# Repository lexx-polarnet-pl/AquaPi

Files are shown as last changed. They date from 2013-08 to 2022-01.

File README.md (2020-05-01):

# AquaPi

The aim of this project is to build Raspberry Pi controlled platform for aquarium management.

## Table of contents
* [General info](#general-info)
* [Screenshots](#screenshots)
* [Versions](#Versions)
* [Setup](#setup)
* [Features](#features)
* [Status](#status)
* [Inspiration](#inspiration)
* [Contact](#contact)

## General info
This project is licensed using GPL 2.0 version.
It's combination of hardware layer and software as well.
Structure of directories is following:

* Software - source codes of daemon and php web ui.
* Hardware - all hardware designs (created using KiCad).
* Doc      - place for documentation.

You can like it or not, but software is written (and documentation as well) in Polish language.

## Screenshots
Main screen

## Versions
* Version 1.0 - still one and only stable version that was released.
* Version 2.0 - aka still in development phase - far more advanced than previous one, but also still not finished (but quite stable).

## Setup
Please see Doc directory if you wish to learn more about setup process.

## Features
List of features ready:
* Heating/cooling tank with different temperature settings between night and day.
* Light control with PWM usage to simulate sunrise/dawn.
* Recording of statistical data collected from sensors into database, and visualization on charts.
* Can be controlled using web browser, both on PC and mobile phone.
* Outputs controlled with timers with 1 second accuracy (nice for DIY feeders or fertilizers).

TODOs for future development:
* still some stuff to do with CO&#8322;.
* and probably more small staff to do.

## Status
Project is: in progress.

## Inspiration
This project was inspired by [Aquamat](https://github.com/musashimm/aquamat). 

## Contact
Created by [lexx](mailto:lexx@polarnet.pl) (https://lexx.polarnet.pl/) - feel free to contact me!
AquaPi is also having its own home page - see https://aquapi.polarnet.pl/

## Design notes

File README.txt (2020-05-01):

AquaPi
======

Ten projekt ma na celu zbudowanie interface'u (sprzętowego i oprogramowania)
tak, aby zamienić Raspberry Pi w komputer sterujący akwarium.

Wszystkie źródła są objęte licencją GPLv2.

Katalogi:

* Software - miejsce na kody źródłowe (daemona oraz interface php)
* Hardware - miejsce na schematy sprzętu
* Doc      - miejsce na dokumentację

Schematy jak i płytki projektowane są w KiCad

Pozdrawiam,
Marcin 'Lexx' Król
http://lexx.polarnet.pl
lexx@polarnet.pl

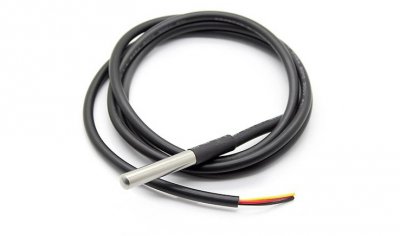
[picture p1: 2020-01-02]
Doc/html/hardware/DS18B20-wp.jpg

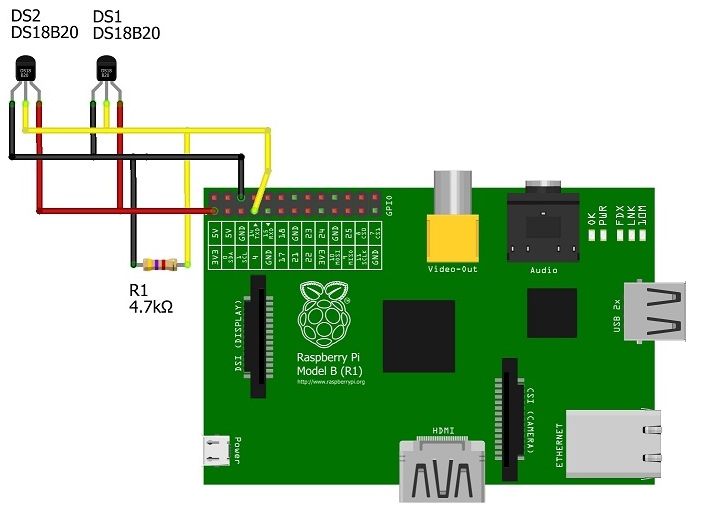
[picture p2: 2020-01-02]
Doc/html/hardware/DS18B20-wire.jpg

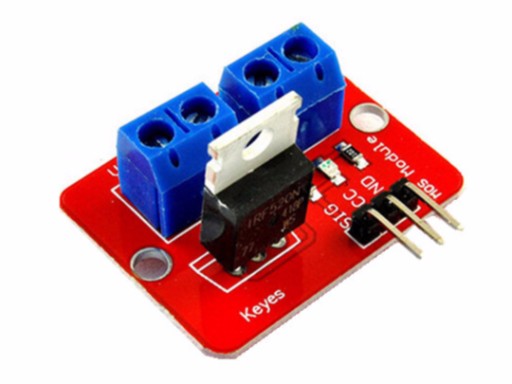
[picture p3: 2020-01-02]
Doc/html/hardware/MOSFET.jpg

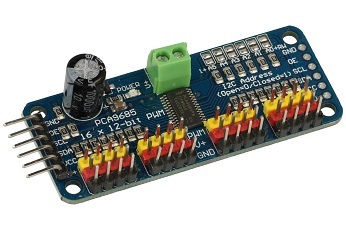
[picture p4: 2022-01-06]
Doc/html/hardware/PCA9685.jpg

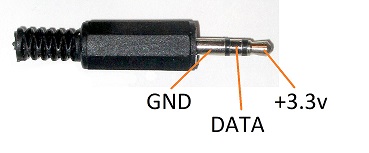
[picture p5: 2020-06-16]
Doc/html/hardware/AQUAPI_connector_jack3.5.jpg

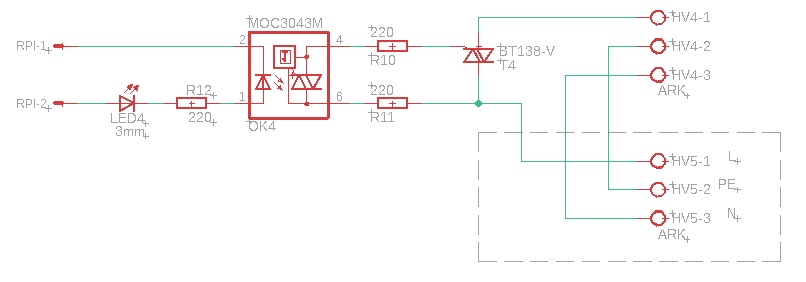
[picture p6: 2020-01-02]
Doc/html/hardware/TRIAK-wire.jpg

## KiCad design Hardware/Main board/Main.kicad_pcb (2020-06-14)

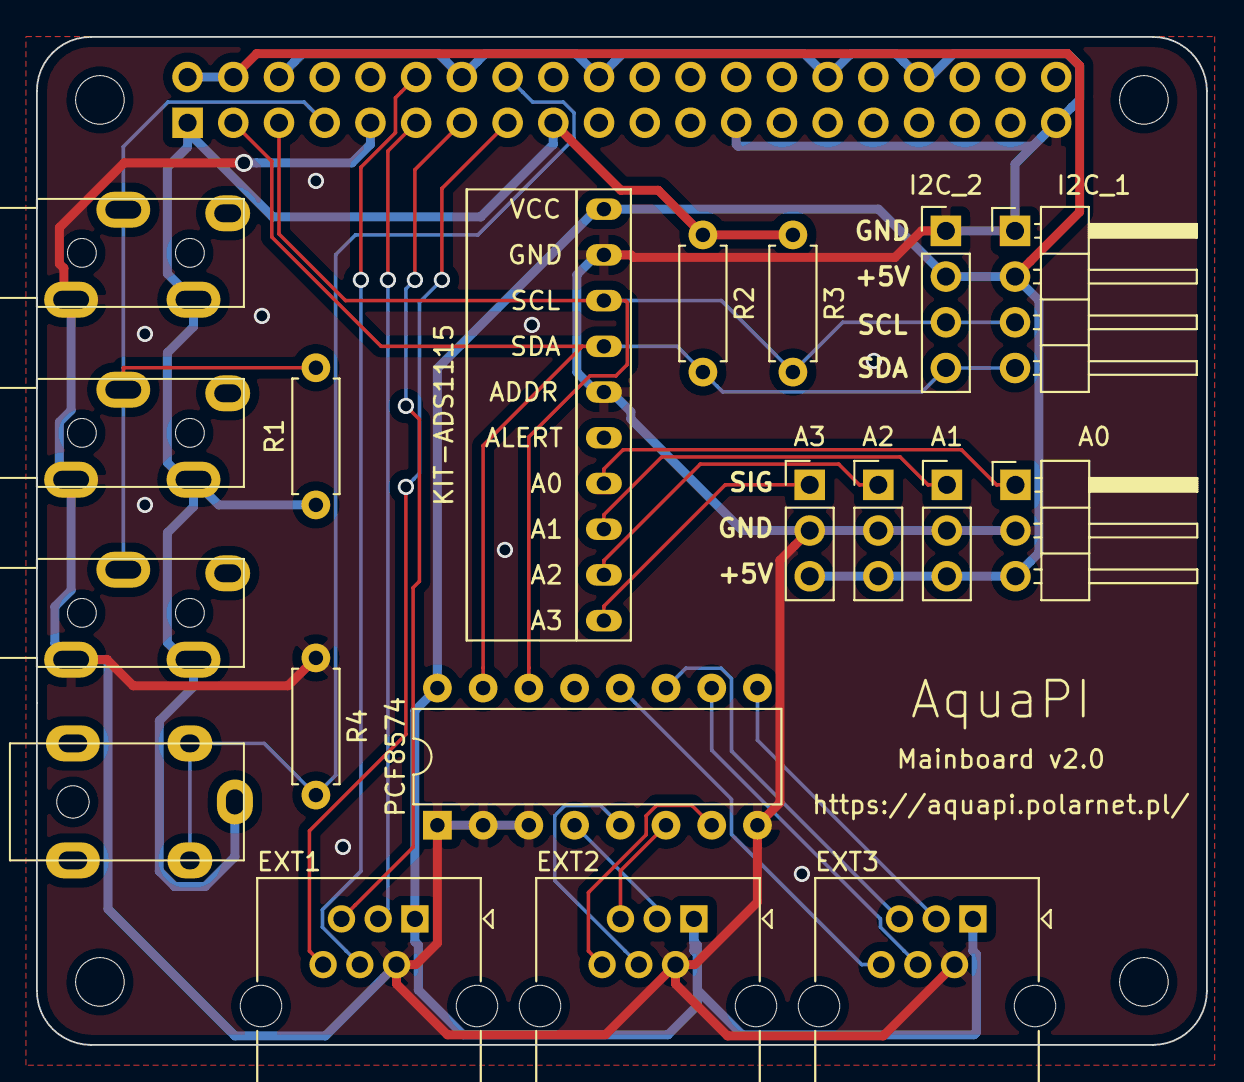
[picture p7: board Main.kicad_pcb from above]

Board: 2 copper layers, 65.0 x 56.0 mm, 24 parts (1 on the bottom side), 23 nets.

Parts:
A0: ADC_A; Pin_Header_Angled_1x03_Pitch2.54mm
A1: ADC_B; Pin_Header_Straight_1x03_Pitch2.54mm
A2: ADC_C; Pin_Header_Straight_1x03_Pitch2.54mm
A3: ADC_D; Pin_Header_Straight_1x03_Pitch2.54mm
EXT1, EXT2, EXT3: RJ12; RJ25_Wayconn_MJEA-660X1_Horizontal
I2C_1: Conn_01x04_Male; Pin_Header_Angled_1x04_Pitch2.54mm
I2C_2: Conn_01x04_Male; Pin_Header_Straight_1x04_Pitch2.54mm
J1, J2, J3: PJ-327
J4: Barrel_Jack_Switch; DC-1GDC1.7_4.0K2
KIT-ADS1115: ADS1115IDGS; ADS1115-KIT
MK1, MK2, MK3, MK4: M2.5; MountingHole_2.7mm_M2.5
P1: Conn_02x20_Odd_Even; PinSocket_2x20_P2.54mm_Vertical
PCF8574: PCF8574; DIP-16_W7.62mm
R1, R2, R3, R4: 4,7k; R_Axial_DIN0207_L6.3mm_D2.5mm_P7.62mm_Horizontal

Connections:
+3V3: J1.3, J2.3, J3.3, J4.1, P1.1, P1.17, R1.1, R2.1, R3.1
+5V: A0.3, A1.3, A2.3, A3.3, EXT1.1, EXT2.1, EXT3.1, I2C_1.2, I2C_2.2, KIT-ADS1115.8, P1.2, P1.4, PCF8574.16
/GPIO2(SDA1): I2C_1.4, I2C_2.4, KIT-ADS1115.9, P1.3, PCF8574.15, R2.2
/GPIO3(SCL1): I2C_1.3, I2C_2.3, KIT-ADS1115.10, P1.5, PCF8574.14, R3.2
/GPIO4(GCLK): J1.2, J2.2, J3.2, P1.7, R1.2
/GPIO17(GEN0): EXT1.3, P1.11
/GPIO18(GEN1)(PWM0): EXT1.4, P1.12
/GPIO22(GEN3): EXT1.6, P1.15
/GPIO23(GEN4): J4.2, J4.3, P1.16, R4.2
/GPIO27(GEN2): EXT1.5, P1.13
GND: A0.2, A1.2, A2.2, A3.2, EXT1.2, EXT2.2, EXT3.2, I2C_1.1, I2C_2.1, J1.1, J2.1, J3.1, KIT-ADS1115.1, KIT-ADS1115.3, P1.6, P1.9, P1.14, P1.20, P1.25, P1.30, P1.34, P1.39, PCF8574.1, PCF8574.2, PCF8574.3, PCF8574.8, R4.1
unnamed: A0.1, KIT-ADS1115.4
unnamed: A1.1, KIT-ADS1115.5
unnamed: A2.1, KIT-ADS1115.6
unnamed: A3.1, KIT-ADS1115.7
unnamed: EXT2.3, PCF8574.4
unnamed: EXT2.4, PCF8574.5
unnamed: EXT2.5, PCF8574.6
unnamed: EXT2.6, PCF8574.7
unnamed: EXT3.3, PCF8574.9
unnamed: EXT3.4, PCF8574.10
unnamed: EXT3.5, PCF8574.11
unnamed: EXT3.6, PCF8574.12

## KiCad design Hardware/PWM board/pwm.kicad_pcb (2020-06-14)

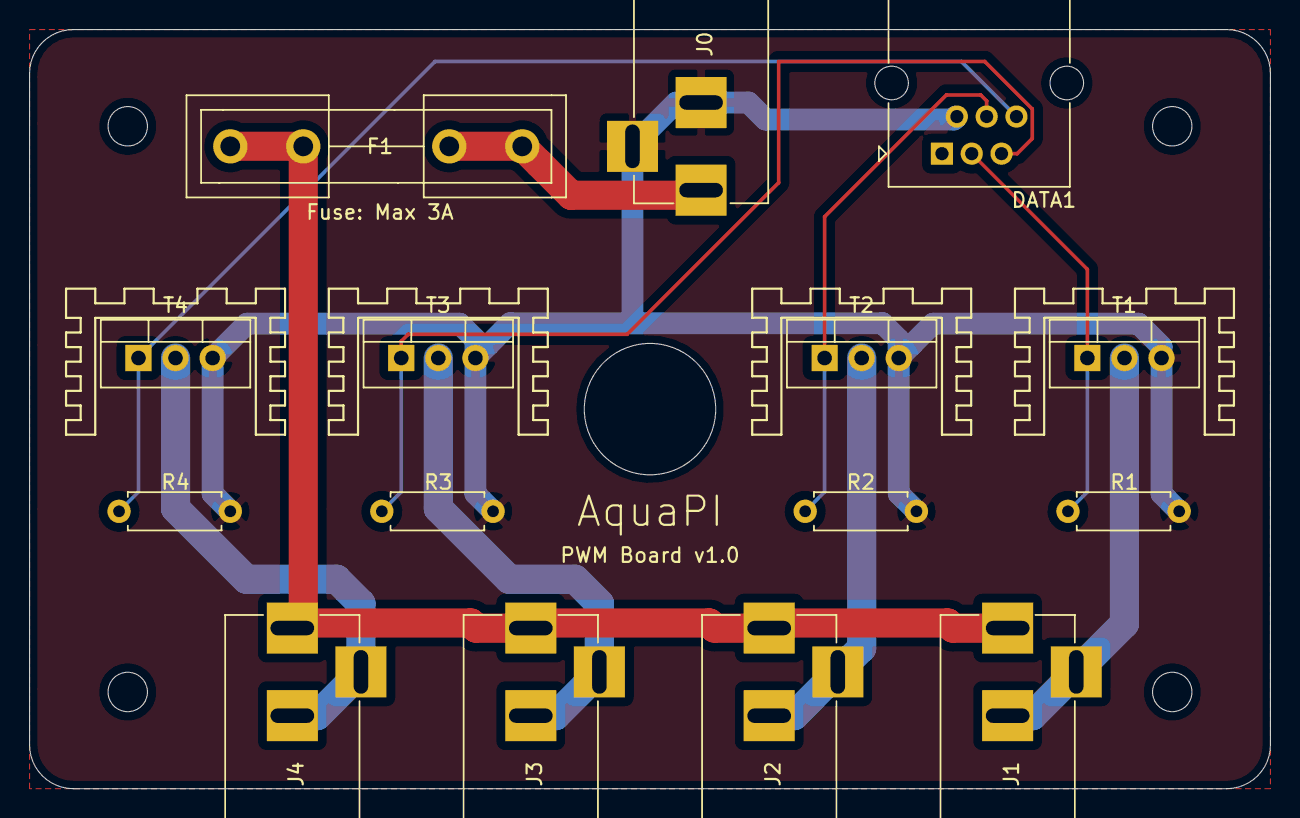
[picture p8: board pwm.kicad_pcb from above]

Board: 2 copper layers, 85.0 x 52.0 mm, 19 parts (0 on the bottom side), 11 nets.

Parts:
DATA1: RJ12; RJ25_Wayconn_MJEA-660X1_Horizontal
F1: Fuse; Fuseholder5x20_horiz_open_inline_Type-I
H1, H2, H3, H4: MountingHole; MountingHole_2.7mm_M2.5
J0, J1, J2, J3, J4: Barrel_Jack_Switch; BARREL_JACK
R1, R2, R3, R4: 4,7k; R_Axial_DIN0207_L6.3mm_D2.5mm_P7.62mm_Horizontal
T1, T2, T3, T4: IRF520; TO-220-3_Vertical

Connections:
+12V: F1.1, J1.1, J2.1, J3.1, J4.1
/PWM1: J1.2, J1.3, T1.2
/PWM2: J2.2, J2.3, T2.2
/PWM3: J3.2, J3.3, T3.2
/PWM4: J4.2, J4.3, T4.2
/SIG1: DATA1.3, R1.2, T1.1
/SIG2: DATA1.4, R2.2, T2.1
/SIG3: DATA1.5, R3.2, T3.1
/SIG4: DATA1.6, R4.2, T4.1
GND: DATA1.2, J0.2, J0.3, R1.1, R2.1, R3.1, R4.1, T1.3, T2.3, T3.3, T4.3
unnamed: F1.2, J0.1

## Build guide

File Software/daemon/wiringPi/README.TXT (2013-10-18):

wiringPi README
===============

Please note that the official way to get wiringPi is via git from
git.drogon.net and not GitHub.

ie.

  git clone git://git.drogon.net/wiringPi

The version of wiringPi held on GitHub by "Gadgetoid" is used to build the
wiringPython, Ruby, Perl, etc. wrappers for these other languages. This
version may lag the official Drogon release.  Pull requests may not be
accepted to Github....

Please see

  http://wiringpi.com/

for the official documentation, etc. and the best way to submit bug reports, etc.
is by sending an email to projects@drogon.net

Thanks!

  -Gordon

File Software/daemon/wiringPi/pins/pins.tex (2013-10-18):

\documentclass[12pt,a4paper]{article}
\parskip 1ex
\parindent 0em
\thispagestyle{empty}
\pagestyle{plain}
\pagenumbering{arabic}
\setlength{\topmargin}{0pt}
\setlength{\headheight}{0pt}
\setlength{\headsep}{0pt}
\setlength{\topskip}{0pt}
\setlength{\textheight}{240mm}
\setlength{\footskip}{5ex}
\setlength{\oddsidemargin}{0pt}
\setlength{\evensidemargin}{0pt}
\setlength{\textwidth}{160mm}
\usepackage[dvips]{graphics,color}
\usepackage{helvet}
\renewcommand{\familydefault}{\sfdefault}
\begin{document}
\begin{sffamily}
\definecolor{rtb-black}{rgb}  {0.0, 0.0, 0.0}
\definecolor{rtb-navy}{rgb}   {0.0, 0.0, 0.5}
\definecolor{rtb-green}{rgb}  {0.0, 0.5, 0.0}
\definecolor{rtb-teal}{rgb}   {0.0, 0.5, 0.5}
\definecolor{rtb-maroon}{rgb} {0.5, 0.0, 0.0}
\definecolor{rtb-purple}{rgb} {0.5, 0.0, 0.5}
\definecolor{rtb-olive}{rgb}  {0.5, 0.5, 0.0}
\definecolor{rtb-silver}{rgb} {0.7, 0.7, 0.7}
\definecolor{rtb-grey}{rgb}   {0.5, 0.5, 0.5}
\definecolor{rtb-blue}{rgb}   {0.0, 0.0, 1.0}
\definecolor{rtb-lime}{rgb}   {0.0, 1.0, 0.0}
\definecolor{rtb-aqua}{rgb}   {0.0, 1.0, 1.0}
\definecolor{rtb-red}{rgb}    {1.0, 0.0, 0.0}
\definecolor{rtb-fuchsia}{rgb}{1.0, 0.0, 1.0}
\definecolor{rtb-yellow}{rgb} {1.0, 1.0, 0.0}
\definecolor{rtb-white}{rgb}  {1.0, 1.0, 1.0}

\begin{center}
\bfseries{WiringPi: GPIO Pin Numbering Tables}\\
\tt{http://wiringpi.com/}
\end{center}

\begin{center}
\begin{tabular}{|c|c|c||p{8mm}|p{8mm}||c|c|c|c|}
\hline
\multicolumn{8}{|c|}{\bfseries{P1: The Main GPIO connector}}\\
\hline
\hline
WiringPi Pin	& BCM GPIO	& Name	& \multicolumn{2}{|c||}{Header}	& Name	& BCM GPIO	& WiringPi Pin\\
\hline
\hline
	& 			& \textcolor{rtb-red}{3.3v}	& \raggedleft{1} &  2 & \textcolor{rtb-maroon}{5v}	& 	& \\
\hline
8	& Rv1:0 - Rv2:2		& \textcolor{rtb-aqua}{SDA}	& \raggedleft{3} &  4 & \textcolor{rtb-maroon}{5v}	& 	& \\
\hline
9	& Rv1:1 - Rv2:3		& \textcolor{rtb-aqua}{SCL}	& \raggedleft{5} &  6 & \textcolor{rtb-black}{0v}	& 	& \\
\hline
7	& 4			& \textcolor{rtb-green}{GPIO7}	& \raggedleft{7} &  8 & \textcolor{rtb-yellow}{TxD}	& 14    & 15\\
\hline
	& 			& \textcolor{rtb-black}{0v}	& \raggedleft{9} & 10 & \textcolor{rtb-yellow}{RxD}	& 15	& 16\\
\hline
0	& 17			& \textcolor{rtb-green}{GPIO0}	& \raggedleft{11} & 12 & \textcolor{rtb-green}{GPIO1}	& 18	& 1\\
\hline
2	& Rv1:21 - Rv2:27	& \textcolor{rtb-green}{GPIO2}	& \raggedleft{13} & 14 & \textcolor{rtb-black}{0v}	& 	& \\
\hline
3	& 22			& \textcolor{rtb-green}{GPIO3}	& \raggedleft{15} & 16 & \textcolor{rtb-green}{GPIO4}	& 23	& 4\\
\hline
	& 			& \textcolor{rtb-red}{3.3v}	& \raggedleft{17} & 18 & \textcolor{rtb-green}{GPIO5}	& 24	& 5\\
\hline
12	& 10			& \textcolor{rtb-teal}{MOSI}	& \raggedleft{19} & 20 & \textcolor{rtb-black}{0v}	& 	& \\
\hline
13	& 9			& \textcolor{rtb-teal}{MISO}	& \raggedleft{21} & 22 & \textcolor{rtb-green}{GPIO6}	& 25	& 6\\
\hline
14	& 11			& \textcolor{rtb-teal}{SCLK}	& \raggedleft{23} & 24 & \textcolor{rtb-teal}{CE0}	& 8	& 10\\
\hline
	& 			& \textcolor{rtb-black}{0v}	& \raggedleft{25} & 26 & \textcolor{rtb-teal}{CE1}	& 7	& 11\\
\hline
\hline
WiringPi Pin	& BCM GPIO	& Name	& \multicolumn{2}{|c||}{Header}	& Name	& BCM GPIO	& WiringPi Pin\\
\hline
\end{tabular}
\end{center}

Note the differences between Revision 1 and Revision 2 Raspberry
Pi's. The Revision 2 is readily identifiable by the presence of the 2
mounting holes.

The revision 2 Raspberry Pi has an additional GPIO connector, P5, which is next to the main P1 GPIO
connector:

\begin{center}
\begin{tabular}{|c|c|c||p{8mm}|p{8mm}||c|c|c|c|}
\hline
\multicolumn{8}{|c|}{\bfseries{P5: Secondary GPIO connector (Rev. 2 Pi only)}}\\
\hline
\hline
WiringPi Pin	& BCM GPIO	& Name	& \multicolumn{2}{|c||}{Header}	& Name	& BCM GPIO	& WiringPi Pin\\
\hline
\hline
	& 		& \textcolor{rtb-maroon}{5v}	& \raggedleft{1} &  2 & \textcolor{rtb-red}{3.3v}	& 	&	\\
\hline
17	& 28		& \textcolor{rtb-green}{GPIO8}	& \raggedleft{3} &  4 & \textcolor{rtb-green}{GPIO9}	& 29	& 18	\\
\hline
19	& 30		& \textcolor{rtb-green}{GPIO10}	& \raggedleft{5} &  6 & \textcolor{rtb-green}{GPIO11}	& 31	& 20	\\
\hline
	& 		& \textcolor{rtb-black}{0v}	& \raggedleft{7} &  8 & \textcolor{rtb-black}{0v}	& 	&	\\
\hline
\hline
WiringPi Pin	& BCM GPIO	& Name	& \multicolumn{2}{|c||}{Header}	& Name	& BCM GPIO	& WiringPi Pin\\
\hline
\end{tabular}
\end{center}

\end{sffamily}
\end{document}

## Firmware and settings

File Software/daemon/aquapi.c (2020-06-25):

/*
 * AquaPi - sterownik akwariowy oparty o Raspberry Pi
 *
 * Copyright (C) 2012-2020 AquaPi Developers
 *
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
 */
 
#include <stdio.h>
#include <stdlib.h>
#include <string.h>
#include <wiringPi.h>
#include <unistd.h>
#include <time.h>
#include <sys/time.h>
#include <syslog.h>
#include <mysql.h>
#include <signal.h>
#include "aquapi.h"
#include "tcpip.c"
#include "database.c"
#include "externals.c"
#include "inifile.c"
#include "light.c"
#include "temperature.c"
#include "co2.c"
#include "timers.c"
#include "alarms.c"
#include "email.c"
#include "calibration.c"

void termination_handler(int signum)	{
	if( signum ) {
		syslog(LOG_ERR, "Daemon exited abnormally.");
		//Log("Praca daemona została przerwana",E_CRIT);
	} else {
		syslog(LOG_INFO, "Daemon exited.");
		Log("Daemon zakończył pracę",E_WARN);
	}
	exit(signum);
}

void Log(char *msg, int lev) {
	time_t rawtime;
	struct tm * timeinfo;
	char timef[80];
	char query[120];
	
	time ( &rawtime );
	
	// log na ekran
	if ( config.dontfork ) {
		timeinfo = localtime ( &rawtime );
		strftime (timef,80,"%H:%M:%S",timeinfo);
		printf("\x1b[33m[%s] ",timef);	// timestamp na żółto
		if (lev==E_DEV) {
				printf("\x1b[34mDEVEL ");
		} else if (lev==E_INFO) {
				printf("\x1b[32mINFO  ");
		} else if (lev==E_WARN) {
				printf("\x1b[33mWARN  ");
		} else if (lev==E_CRIT) {
				printf("\x1b[31mCRIT  ");
		} else if (lev==E_SQL) {
				printf("\x1b[31mSQLER ");
		}
		printf("\x1b[39m%s\n",msg);
	}
	
	if (lev >= 0 && lev != E_SQL) {
		sprintf(query,"INSERT INTO logs (log_date,log_level,log_value) VALUES (%ld,%i,'%s')",rawtime,lev,msg);
		DB_Query(query);
	}
	
	// Tego rodzaju błędy wrzucaj w sysloga
	if ((lev == E_SQL) || (lev == E_CRIT) || (lev == E_WARN)) {
		syslog(LOG_ERR, msg);
	}
	// na sam koniec, wyślij logi krytyczne na maila
	if (lev == E_CRIT) {
		email_error(msg,lev);
	}	
}

void StoreTempStat() {
	time_t rawtime;
	char buff[200];
	time ( &rawtime );
	int x;

	for(x = 0; x <= interfaces_count; x++) {
		if (interfaces[x].type == DEV_INPUT) {
			if (interfaces[x].measured_value > -100) {
				sprintf(buff,"INSERT INTO stats (stat_date, stat_interfaceid, stat_value) VALUES (%ld, %d, %.2f)",rawtime, interfaces[x].id, interfaces[x].measured_value);
				DB_Query(buff);
			} else {
				sprintf(buff,"INSERT INTO stats (stat_date, stat_interfaceid, stat_value) VALUES (%ld, %d, null)",rawtime, interfaces[x].id);
				DB_Query(buff);
			}
		}
	}
}

void ReadConf() {
	MYSQL_RES *result;
	MYSQL_ROW row;
	int x;
	char buff[200];

	Log("Odczyt konfiguracji",E_DEV);
	
	// Wczytanie interface'ów
	Log("Wczytanie interface'ów",E_DEV);
	interfaces_count = -1;
	DB_Query("SELECT interface_id,interface_address,interface_name,interface_type,interface_conf,interface_draw,interface_service_val,interface_dashboard FROM interfaces WHERE interface_deleted = 0");
	result = mysql_store_result(conn);
	while ((row = mysql_fetch_row(result))) {
		interfaces_count++;
		interfaces[interfaces_count].id = atof(row[0]);
		memcpy(interfaces[interfaces_count].address,row[1],sizeof(interfaces[interfaces_count].address));
		memcpy(interfaces[interfaces_count].name,row[2],sizeof(interfaces[interfaces_count].name));
		interfaces[interfaces_count].type = atof(row[3]);
		if (row[4] != NULL) {
			interfaces[interfaces_count].conf = atof(row[4]);
		} else {
			interfaces[interfaces_count].conf = 0;
		}
		interfaces[interfaces_count].draw = atof(row[5]);
		interfaces[interfaces_count].service_val = atof(row[6]);
		interfaces[interfaces_count].dashboard = atof(row[7]);
	}	
	mysql_free_result(result);
	
	// domyślnie wyjścia na stan nieustalony
	for(x = 0; x <= interfaces_count; x++) {
		if (interfaces[x].type == DEV_OUTPUT || interfaces[x].type == DEV_OUTPUT_PWM) {
			interfaces[x].state = -1;
			interfaces[x].new_state = -1;
			interfaces[x].override_value = -1;
			interfaces[x].override_expire = -1;
			interfaces[x].was_error_last_time = -1;
		}
		if (interfaces[x].type == DEV_INPUT) {
			interfaces[x].measured_value = -200;
			interfaces[x].was_error_last_time = -1;
		}		
	}

	// wczytanie konfiguracji pozostałych modułów
	ModTimers_ReadSettings();
	ModLight_ReadSettings();
	ModTemperature_ReadSettings();
	ModCo2_ReadSettings();
	ModAlarms_ReadSettings();
	email_ReadSettings();
	Calibration_ReadSettings();
	
	DB_GetSetting("service_mode_input",buff);
	specials.service_mode_input = atof(buff);	
	
	Log("Konfiguracja odczytana",E_DEV);

	SetupPorts();
}

void ProcessPortStates() {
	int x;
	char buff[200];
	time_t rawtime;
	time ( &rawtime );

	for(x = 0; x <= interfaces_count; x++) {
		//zacznij od sprawdzenia czy pracujemy w trybie auto
		if (interfaces[x].override_value != -1) {
			// tryb manualny
			if (interfaces[x].state != interfaces[x].override_value) {
				// konieczna jest zmiana stanu wyjścia
				interfaces[x].state = interfaces[x].override_value;					
				if (interfaces[x].type == DEV_OUTPUT) {
					if (interfaces[x].conf == 0) {
						ChangePortState(interfaces[x].address,interfaces[x].state);
					} else {
						ChangePortState(interfaces[x].address,1-interfaces[x].state);
					}
					if (interfaces[x].state == 1) {
						sprintf(buff,"Załączam ręcznie %s",interfaces[x].name);
					} else {
						sprintf(buff,"Wyłączam ręcznie %s",interfaces[x].name);
					}
				} else if (interfaces[x].type == DEV_OUTPUT_PWM) {
					if (interfaces[x].conf == 0) {
						ChangePortStatePWM(interfaces[x].address,interfaces[x].state);
					} else {
						ChangePortStatePWM(interfaces[x].address,100-interfaces[x].state);
					}
					sprintf(buff,"Ustawiam ręcznie PWM na %i%% dla wyjścia %s",interfaces[x].state,interfaces[x].name);
				}
				Log(buff,E_INFO);	
				sprintf(buff,"INSERT INTO stats (stat_date, stat_interfaceid, stat_value) VALUES (%ld, %d, %i)",rawtime, interfaces[x].id, interfaces[x].state);
				DB_Query(buff);				
			}
		} else if (specials.is_service_mode == 1 && interfaces[x].service_val != -1) {
			// ustawienie wartości wyjść na tryb serwisowy
			if (interfaces[x].state != interfaces[x].service_val) {
				// konieczna jest zmiana stanu wyjścia
				interfaces[x].state = interfaces[x].service_val;					
				if (interfaces[x].type == DEV_OUTPUT) {
					if (interfaces[x].conf == 0) {
						ChangePortState(interfaces[x].address,interfaces[x].state);
					} else {
						ChangePortState(interfaces[x].address,1-interfaces[x].state);
					}
					if (interfaces[x].state == 1) {
						sprintf(buff,"Załączam %s w trybie serwisowym",interfaces[x].name);
					} else {
						sprintf(buff,"Wyłączam %s w trybie serwisowym",interfaces[x].name);
					}
				} else if (interfaces[x].type == DEV_OUTPUT_PWM) {
					if (interfaces[x].conf == 0) {
						ChangePortStatePWM(interfaces[x].address,interfaces[x].state);
					} else {
						ChangePortStatePWM(interfaces[x].address,100-interfaces[x].state);
					}
					sprintf(buff,"Ustawiam PWM na %i%% dla wyjścia %s w trybie serwisowym",interfaces[x].state,interfaces[x].name);
				}
				Log(buff,E_INFO);	
				sprintf(buff,"INSERT INTO stats (stat_date, stat_interfaceid, stat_value) VALUES (%ld, %d, %i)",rawtime, interfaces[x].id, interfaces[x].state);
				DB_Query(buff);				
			}			
		} else {
			if ((interfaces[x].state != interfaces[x].new_state) && (interfaces[x].new_state != -1)) {
				// konieczna jest zmiana stanu wyjścia
				interfaces[x].state = interfaces[x].new_state;
				if (interfaces[x].type == DEV_OUTPUT) {
					if (interfaces[x].conf == 0) {
						ChangePortState(interfaces[x].address,interfaces[x].state);
					} else {
						ChangePortState(interfaces[x].address,1-interfaces[x].state);
					}
					if (interfaces[x].state == 1) {
						sprintf(buff,"Załączam %s",interfaces[x].name);
					} else {
						sprintf(buff,"Wyłączam %s",interfaces[x].name);
					}
				}
				if (interfaces[x].type == DEV_OUTPUT_PWM) {
					if (interfaces[x].conf == 0) {
						ChangePortStatePWM(interfaces[x].address,interfaces[x].state);
					} else {
						ChangePortStatePWM(interfaces[x].address,100-interfaces[x].state);
					}
					sprintf(buff,"Ustawiam PWM na %i%% dla wyjścia %s",interfaces[x].state,interfaces[x].name);
				} 
				Log(buff,E_INFO);	
				sprintf(buff,"INSERT INTO stats (stat_date, stat_interfaceid, stat_value) VALUES (%ld, %d, %i)",rawtime, interfaces[x].id, interfaces[x].state);
				DB_Query(buff);				
			}
		}
	}	
}

void Externals_Debug() {
	char buff[200];
	int x;
	Log("════════════════════════ Zrzut interfaceów ════════════════════════",E_DEV);
	Log("┌───┬───────┬───────┬────┬────────────────────────────── Wejścia ──",E_DEV);
	Log("│ID │Wartość│Surowa │Błąd│Nazwa",E_DEV);
	Log("├───┼───────┼───────┼────┼─────────────────────────────────────────",E_DEV);				
	for(x = 0; x <= interfaces_count; x++) {
		if (interfaces[x].type == DEV_INPUT) {
			sprintf(buff,"│%3i│%+7.1f│%+7.1f│%4i│%s",interfaces[x].id,interfaces[x].measured_value,interfaces[x].raw_measured_value,interfaces[x].was_error_last_time,interfaces[x].name);
			Log(buff,E_DEV);
		}
	}	
	Log("└───┴───────┴───────┴────┴─────────────────────────────────────────",E_DEV);	
	Log("┌───┬──────┬──────┬──────┬─────┬─────┬────┬───────────── Wyjścia ──",E_DEV);
	Log("│ID │Stan  │NowySt│ Conf │Overr│OvExp│Błąd│Nazwa",E_DEV);
	Log("├───┼──────┼──────┼──────┼─────┼─────┼────┼────────────────────────",E_DEV);				
	for(x = 0; x <= interfaces_count; x++) {
		if (interfaces[x].type == DEV_OUTPUT) {
			sprintf(buff,"│%3i│%6i│%6i│%+6.1f│%5i│%5i│%4i│%s",interfaces[x].id,interfaces[x].state,interfaces[x].new_state,interfaces[x].conf,interfaces[x].override_value,interfaces[x].override_expire,interfaces[x].was_error_last_time,interfaces[x].name);
			Log(buff,E_DEV);
		}
	}					
	Log("└───┴──────┴──────┴──────┴─────┴─────┴────┴────────────────────────",E_DEV);		
	Log("┌───┬──────┬──────┬──────┬─────┬─────┬────┬───────── Wyjścia PWM ──",E_DEV);
	Log("│ID │Stan  │NowySt│ Conf │Overr│OvExp│Błąd│Nazwa",E_DEV);
	Log("├───┼──────┼──────┼──────┼─────┼─────┼────┼────────────────────────",E_DEV);				
	for(x = 0; x <= interfaces_count; x++) {
		if (interfaces[x].type == DEV_OUTPUT_PWM) {
			sprintf(buff,"│%3i│%6i│%6i│%+6.1f│%5i│%5i│%4i│%s",interfaces[x].id,interfaces[x].state,interfaces[x].new_state,interfaces[x].conf,interfaces[x].override_value,interfaces[x].override_expire,interfaces[x].was_error_last_time,interfaces[x].name);
			Log(buff,E_DEV);
		}
	}					
	Log("└───┴──────┴──────┴──────┴─────┴─────┴────┴────────────────────────",E_DEV);	
}

//void catch_alarm(int sig) {
void process() {
	int x;
	time_t rawtime;
	struct tm * timeinfo;
	
	time ( &rawtime );
	timeinfo = localtime ( &rawtime );	
	// użyjemy tej procedury żeby łapać wywołanie systemowe, i ustawimy timer żeby wykonywała się co sekundę żeby móc procesować rzeczy związane z obsługą AquaPi
	
	// ustalenie timerów i ustalenie czy jest dzien czy noc
	time ( &rawtime );
	timeinfo = localtime ( &rawtime );
	specials.seconds_since_midnight = timeinfo->tm_hour * 3600 + timeinfo->tm_min * 60 + timeinfo->tm_sec;

	// sprawdź czy w tej sekundzie już sprawdzałeś timery i resztę, lub czy nie otrzymałeś komendy z zewnątrz na którą trzeba zareagować
	if (specials.seconds_since_midnight != specials.last_sec_run) {
		// nie sprawdzałeś, to sprawdzaj
		specials.last_sec_run = specials.seconds_since_midnight;

		// obsługa wejść
		if (specials.seconds_since_midnight % config.inputs_freq == 0) {
			for(x = 0; x <= interfaces_count; x++) {
				if (interfaces[x].type == DEV_INPUT) {
					interfaces[x].raw_measured_value = GetDataFromInput(x);
				}
			}
		}
		// nałóż na odczytane dane kalibrację czujników
		Calibration_Process();
		
		// Załatw ustawienia oświetlenia, temperatury i co2
		ModTimers_Process();
		ModLight_Process();
		ModTemperature_Process();
		ModCo2_Process();
		ModAlarms_Process();
		
		// Tryb serwisowy
		if (specials.is_service_mode == 0 && GetValFromInterface(specials.service_mode_input) > 0.5) {
			specials.is_service_mode = 1;
			Log("Wchodzę w tryb serwisowy",E_INFO);
		}
		if (specials.is_service_mode == 1 && GetValFromInterface(specials.service_mode_input) < 0.5) {
			specials.is_service_mode = 0;
			Log("Wychodzę z trybu serwisowego",E_INFO);
		}		
		
		// wszystko załatwione, to teraz faktycznie zmień stan portów (jeśli potrzeba)
		ProcessPortStates();
		
		// informacje devel
		if (specials.seconds_since_midnight % config.devel_freq == 0) {
			Externals_Debug();
			ModTimers_Debug();
			ModLight_Debug();
			ModTemperature_Debug();
			ModCo2_Debug();
			ModAlarms_Debug();
			Calibration_Debug();
		}

		//if (specials.seconds_since_midnight % config.stat_freq == 0) {
		if ((specials.seconds_since_midnight > specials.last_sec_store_stat + config.stat_freq) || (specials.seconds_since_midnight < specials.last_sec_store_stat)) {
			specials.last_sec_store_stat = specials.seconds_since_midnight;
			StoreTempStat();
		}

		if ((specials.seconds_since_midnight % config.reload_freq == 0) && (config.reload_freq != -1)) {
			Log("Automatyczne odświerzenie konfiguracji",E_DEV);
			ReadConf();
		}
	}
	
	//signal(sig, catch_alarm);
}

int main() {
	char buff[200];
	//struct itimerval intold;
	//struct itimerval intnew;
	char *pidfile = NULL;
	FILE *pidf;
	int fval = 0;

	// defaults
	config.dontfork 	= 0;
	config.inputs_freq 	= 1;		// co ile sekund kontrolować wejścia
	config.devel_freq 	= 30;		// co ile sekund wypluwać informacje devel
	config.stat_freq 	= 600;		// co ile sekund zapisywac co się dzieje w bazie
	config.reload_freq	= -1;		// co ile robić przeładowanie konfiguracji (-1 oznacza że tylko po otrzymaniu komendy przez TCP)
	config.bind_address	= "127.0.0.1";	// domyślny adres IP na którym demon ma nasłuchiwać połączeń
	config.bind_port	= 6580;		// domyślny port na którym demon ma nasłuchiwać
	
	specials.is_service_mode = 0;

	if (ini_parse("/etc/aquapi.ini", handler, &config) < 0) {
		printf("Can't load '/etc/aquapi.ini'\n");
		exit(1);
	}
	
	openlog(APPNAME, 0, LOG_INFO | LOG_CRIT | LOG_ERR);
	syslog(LOG_INFO, "Daemon started.");

	DB_Init();

	Log("Daemon uruchomiony",E_WARN);
	sprintf(buff,"Kompilacja daemona: %s %s",build_date,build_time);
	Log(buff,E_DEV);
	
	HardwareDetect();
	
	ReadConf();

	if ( !config.dontfork ) {
		fval = fork();
		switch(fval) {
			case -1:
				fprintf(stderr, "Fork error. Exiting.");
				termination_handler(1);
			case 0:
				setsid();
				break;
			default:
				syslog(LOG_INFO, "Daemonize. Forked child %d.", fval);
				if (pidfile != NULL && (pidf = fopen(pidfile, "w")) != NULL) {
					fprintf(pidf, "%d", fval);
					fclose(pidf);
				}
				exit(0); // parent exits
		}
	}

	InitTCP();

	// termination signals handling
	signal(SIGINT, termination_handler);
	signal(SIGTERM, termination_handler);
	/* // timer handler
	signal(SIGALRM, catch_alarm);
	
	// alarm ustawiamy co 1 sekundę a potem przechwytujemy funkcją catch_alarm 
	intnew.it_interval.tv_sec = 1;
	intnew.it_interval.tv_usec = 0;
	intnew.it_value.tv_sec = 1;
	intnew.it_value.tv_usec = 0;

	intold.it_interval.tv_sec = 0;
	intold.it_interval.tv_usec = 0;
	intold.it_value.tv_sec = 0;
	intold.it_value.tv_usec = 0;

	if (setitimer (ITIMER_REAL, &intnew, &intold) < 0)
		Log("Inicjalizacja przerwania zegarowego nieudana",E_CRIT);
	else
		Log("Przerwanie zegarowe zainicjowane",E_DEV);
 
	for (;;) sleep(1); */
	
	for (;;) {
		process();
		usleep(100000);
	}
	
	return 0;
}

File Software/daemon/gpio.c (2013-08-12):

/*
 * AquaPi - sterownik akwariowy oparty o Raspberry Pi
 *
 * Copyright (C) 2012 Marcin Król (lexx@polarnet.pl)
 *
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
 * $Id$
 */
 
#include <wiringPi.h>

const int gpio_heater = 1;
const int gpio_main_light = 4;
const int gpio_uni1 = 0;
const int gpio_uni2 = 6;
const int gpio_cool = 5;

double read_temp(char *sensor_id) {
    FILE *fp;
	
    char sensor_path[200]; 
	char buff[200];
    char line[80];
	char line2[80];
	char *pos;
	double temp;

	sprintf(sensor_path,"/sys/bus/w1/devices/%s/w1_slave",sensor_id);
	
    fp = fopen (sensor_path, "r");
    if( fp == NULL ) {
		sprintf(buff,"Błąd dostępu do %s: %s", sensor_path, strerror(errno));
		Log(buff,E_CRIT);
		return -201;
    } else {
		// otwarty plik z danymi sensora, trzeba odczytac
		fgets(line, 80, fp);
		fgets(line2, 80, fp);
		fclose (fp);		
		// poszukajmy YES w stringu (weryfikacja CRC ok)
		pos = strstr(line,"YES");
		if (pos != NULL) {
			// teraz mamy dane o temperaturze
			pos = strstr(line2,"t=");
			if (pos != NULL) {
				// przesuwamy wzkaznik o 2, na poczatek informacji o temperaturze
				pos += 2;
				temp = (double)atoi(pos)/1000;
				return temp;
			} else {
				return -200;
			}
		} else {
			//sprintf(buff,"Błąd CRC przy odczycie sensora %s", sensor_id);
			//Log(buff,E_WARN);
			return -202;
		}
	}
}

int GPIO_setup() {
	if (wiringPiSetup () == -1) {
		return 1;
	} else {
		pinMode (gpio_main_light, OUTPUT) ;
		pinMode (gpio_heater, OUTPUT) ;
		pinMode (gpio_cool, OUTPUT) ;
		pinMode (gpio_uni1, OUTPUT) ;
		pinMode (gpio_uni2, OUTPUT) ;
		// grzanie i chłodzenie domyślnie wyłączone
		digitalWrite (gpio_heater, 0);
		digitalWrite (gpio_cool, 0);
		return 0;
	}
}

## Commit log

2012-10-13 wersja 0.1 sterownika
    [v1.brd, v1.sch]
2012-10-23 statystyki i początek timerów
2012-11-26 wartości na schemacie
    [v1.brd, v1.sch]
2012-11-26 dopisane kolejne wartości
    [v1.brd, v1.sch]
2012-12-25 poprawki w daemonie (nazwy wyjść i kontrola CRC w odczycie sensora temp)
2013-02-03 początek pracy nad wersją 2.0
    [v2.brd, v2.sch]
2013-02-17 poczatki pracy nad v2.0
    [v2.brd, v2.sch]
2013-03-05 dodane warianty płytek wykonawczych z Aquamatu
    [realys_board_2.brd, relays_board_2.sch, relays_board_4.brd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]
2013-04-14 - uproszczenie & wersja gotowa do testów
    [v2.brd, v2.sch]
2013-04-14 - początki pH metru
    [pH-metr.brd, pH-metr.sch]
2013-04-14 Dodany RTC i reszta brakujących plików
    [rtc.brd, rtc.sch]
2013-08-11 dodanie obsługi 4 sensorów temperatury, przygotowania pod obsługę nowych statystyk
2013-08-12 wyeliminowano problem z too many open files
    [gpio.c]
2013-08-23 kontrola crc przy odczycie temp z sensorów pomocniczych i wyłączenie starych statystyk
2013-10-18 Aktualizacja wiringpi oraz początek zwiększania ilości wyjść
2013-11-07 Update externals.c
    korekta temperatury z czytnika
2013-11-07 Update aquapi.c
    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
2013-11-07 Update aquapi.sql
    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
2013-11-07 Update settings.php
    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
2013-11-07 Update settings.tpl
    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
2013-11-09 demon zapisuje dane z czujników uwzgledniając czujniki zapisane w tabeli sensors
2013-11-09 dodawanie nowych sensorów
2013-11-10 ups schematic diagram
2013-11-10 apka do obsługi RelayBoard www.ucprojects.eu/relay-board
2013-11-10 wstępna obsługa relayboard na poziomie odczytu bazy danych
2013-11-10 przeniesienie apki relayboard we własciwe miejsce
2013-11-10 fix tabeli relayboard
2013-11-11 lekkie poprawki i mozliwosc ustawienia sensora temp jako dummy
2013-11-14 Dodana obsługa relayboard w daemonie
2013-11-14 poprawka na wypadek braku timerów
2013-11-14 nie mozna było dodac sensora ktory nie miał byc pokazywany na wykresie.
2013-11-14 Update aquapi.sql
    rozszerzenie tabeli sensors
2013-11-14 oznaczanie jednego sensora jako master dla zgodnosci z demonem :(
2013-11-14 zmiana w demonie uwzgledniajaca tabele sensors
2013-11-18 dostosowanie dashboard do nowej bazy, dodanie konfigurowalnych ikon dla wyjsc (gpio i relayboard), dodana szczatkowa obsługa ikonek w ustawieniach
2013-11-19 usunięcie zbędnych fragmentów RelayBoard
2013-11-20 sprawdzanie poprawnego odczytu sensorów. błedne odczyty są odrzucane, a zdarzenie logowane
2013-11-22 2 formatki dodawania timerów.
2013-11-24 demon loguje temperatory z czujnika dummy, poprawka aktualizacji sensorów, temperatury nocne. poprawione duperele.
2013-12-29 Podstawowa obsługa timerów (czasowych) jeszcze bez dni tygodnia
2013-12-30 Pozostałe timery też już działają
2014-01-24 poprawka na brakujacy sensor
2014-02-02 demon php ignoruje wyłaczone urzazenia, przystosowanie dashboard do zdalnego/lokalnego demona, parę uproszczeń kodu, utworzenie sekcji do konfiguracji relayboard.
2014-02-11 poprawka master sensora
2014-02-24 Dane z sensorów wejściowych są ponownie zapisywane w bazie jako statystyka
2014-03-15 poprawka zapisywania nowych sensorów do bazy.
2014-03-17 mutex lekarstwem na threads i błędy mysql query + kilka mniejszych
2014-03-18 korekcja nocna temperatury
2014-03-18 mozliwosc uzycia sensorów systemowych w trigerach
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2014-03-20 lokalizacja - zewn temperatura
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2014-04-01 dodanie tabeli gpios
    lista dostepnych par pin-gpio w zaleznosci od rewizji rpi
2014-04-01 dodanie konfigurowalnych jednostek dla sensorów
2014-04-06 https://github.com/lexx-polarnet-pl/AquaPi/issues/21
    sensor głowny wyswietla sie na dashboard
2014-04-06 Update aquapi.sql
    dodanie sprzetowego pwm z gpio18 do bazy
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2014-04-06 trigery pwm w UI
2014-07-04 Dodana nowa komenda RPC aquapi:devicelist
2014-07-21 dodatkowa poprawka na relayboard, brak opóźnienia przy braku karty
2014-07-26 Początki obsługi ekspandera i2c
2014-08-01 Dodana (wstępna bo czekam na sondę) obsługa modułu miniPh (pomiar pH) oraz wyczyszczenie i poprawa obsługi expanderów i2c opartych o pcf8574
2014-08-01 Poprawki w obsłudze i2c
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2014-08-03 Żegnaj temp_freq i witaj inputs_freq - w koncu oprócz sensorów temp obsługujemy również sondę pH i wejścia cyfrowe Dodatkowo default refresh co 1 sek (bo 10 sek zwłoki przy automatycznej dolewce mogł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
2018-04-07 inne ikonki + sterowanie temperaturą w UI
2018-04-10 obsługa temperatury w daemonie
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2018-12-03 jeszcze kilka zmian w pwm
2018-12-15 zmiany w timerach i ikonkach
2020-01-02 dodanie opisu podłączenia urządzeń w dokumentacji
    [ds18b20.fzz, miniph.fzz, pcf8574.fzz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]
2020-02-29 dodana możliwość nastaw ręcznych dla portu PWM
2020-03-01 poprawka w ręcznych nastawach PWM
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2020-04-20 zmiana w nazewnictwie pinów mostka ADC
2020-05-01 skasowanie starych wersji płytek
    [pH-metr.brd, pH-metr.sch, realys_board_2.brd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]
2020-05-01 nowa płyta główna
    [Main-B_Cu.gbl, Main-B_Mask.gbs, Main-B_Paste.gbp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]
2020-05-01 zmiana Eagle na KiCad
2020-05-01 Poprawki w płycie głównej
    [Main-B_Cu.gbl, Main-B_Mask.gbs, Main-B_Paste.gbp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]
2020-05-03 ominięcie problemu wyświetlania surowych wartości na UI przy pH
    [aquapi.c]
2020-06-14 nowy projekt sprzętu
    [Main-B_Cu.gbl, Main-B_Mask.gbs, Main-B_SilkS.gbo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]
2022-01-06 Dodane zdjęcia zlożonego PWM board
2022-01-06 finalne usunięcie obsługi i powiązań z relayboard

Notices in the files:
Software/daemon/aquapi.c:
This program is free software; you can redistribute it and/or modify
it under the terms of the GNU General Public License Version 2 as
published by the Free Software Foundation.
